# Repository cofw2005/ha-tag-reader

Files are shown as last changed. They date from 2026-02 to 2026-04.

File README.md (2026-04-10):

# Enhanced Home Assistant NFC Tag Reader 🚀

> _**Note:** This project is inspired by [Adonno's Tag Reader](https://github.com/adonno/tagreader). I have first created an original version of Adonno's Tag Reader, and afterwards also added some hardware optimizations for better long-term stability and a slightly modified enclosure specifically for the Type-C D1 Mini._

## 🌟 Overview
This repository provides a refined version of the ESPHome-based NFC Tag Reader. By addressing common electrical limitations and updating the mechanical design for new type-C version D1 Mini board, this project ensures a more robust experience for your smart home automation.

<div align="center">
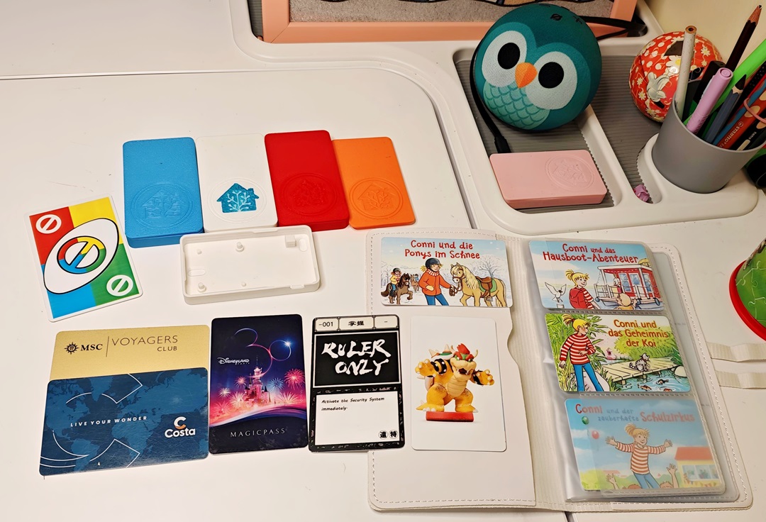
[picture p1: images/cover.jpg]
Family Bucket
  
</div>

---

## 🛠️ Project Evolution & Documentation

I have structured the documentation to guide you through the initial build and the subsequent optimizations:

### 1. [Standard Build Guide](./docs/01.original_build.md)
*Step-by-step instructions following the original Adonno design. Perfect for your first build.*

<div align="center">
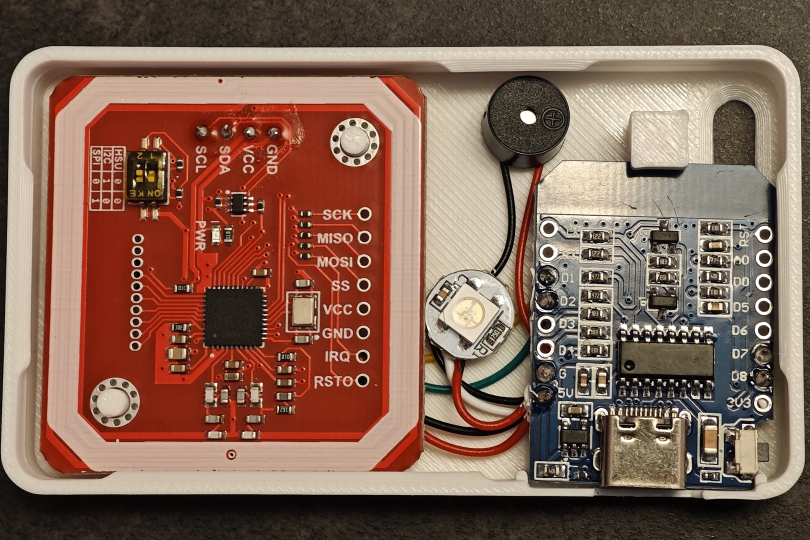
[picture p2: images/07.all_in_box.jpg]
All in box
  
</div>

### 2. [Hardware Optimizations (Recommended)](./docs/02.hardware_optimization.md)
*The "Core" of this repo. Learn what I tested and how I resolved the **1.4V voltage drop** on the buzzer using an S8050 transistor and prevent potential boot issues by reassigning pins.*

<div align="center">
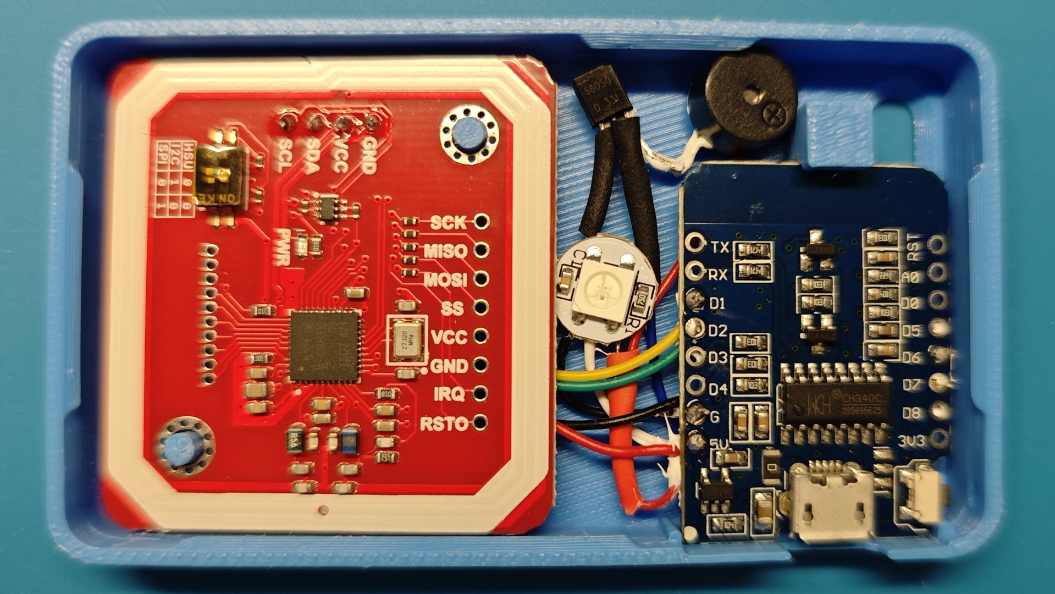
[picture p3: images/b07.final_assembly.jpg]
Final Assembly Result
  
</div>

### 3. [My Applications & Show Off](./docs/03.my_applications.md)
*See the reader in action: custom NFC cards, jukebox automations, and audio triggers.*

<div align="center">
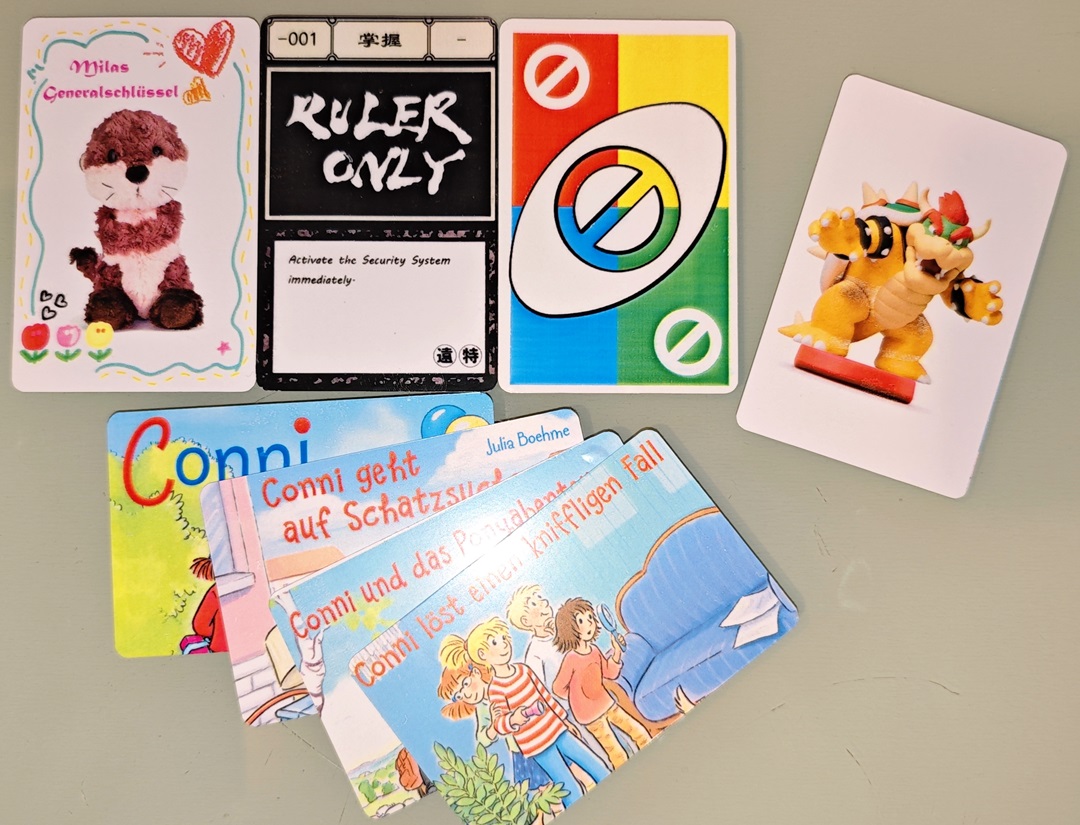
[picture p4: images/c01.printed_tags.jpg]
  
</div>

### 4. Modified Case for type C D1 Mini

I've made some slight modifications to the original STL files from adonno:
1. Adjusted the opening to fit the USB Type-C version of the D1 mini board.
2. I had some minor issues fitting the PN532 board onto the alignment posts, so I shifted one of them by approximately 0.2mm for a better fit.
3. Updated the Home Assistant logo on the top surface to the latest official version.

*See the file in stl folder.*

---

## 🤝 Acknowledgments
- **Adonno**: For the original inspiration and the brilliant base YAML configuration.
- **ESPHome Community**: For the powerful tools that make these projects possible.

---

## 📜 License

This project is licensed under the **GPL-3.0 License** - see the [LICENSE](LICENSE) file for details. 

As a derivative work of [Adonno's Tag Reader](https://github.com/adonno/tagreader), this repository maintains the same GPLv3 terms to ensure the freedom of hardware and software improvements.

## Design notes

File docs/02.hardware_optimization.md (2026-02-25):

# Hardware Optimization: Enhancing Stability & Reliability

> _**Disclaimer:** The original TagReader design works well for most users, and my initial build following that scheme has been operating without any issues. However, based on technical discussions within the community and an analysis of component datasheets, I have proposed the following optimizations from a purely theoretical and long-term reliability perspective. These "patches" aim to further enhance the robustness of the device._

---

## 1. 🔉 Buzzer Drive Optimization (The Transistor Fix)

### The Problem: GPIO Current Limits
In the standard build, the buzzer is driven directly by the **D7 (GPIO13)** pin. 

* **Observation:** During testing, the voltage on D7 dropped to approximately **1.1 ~ 1.6V** when the buzzer was active.

<div align="center">
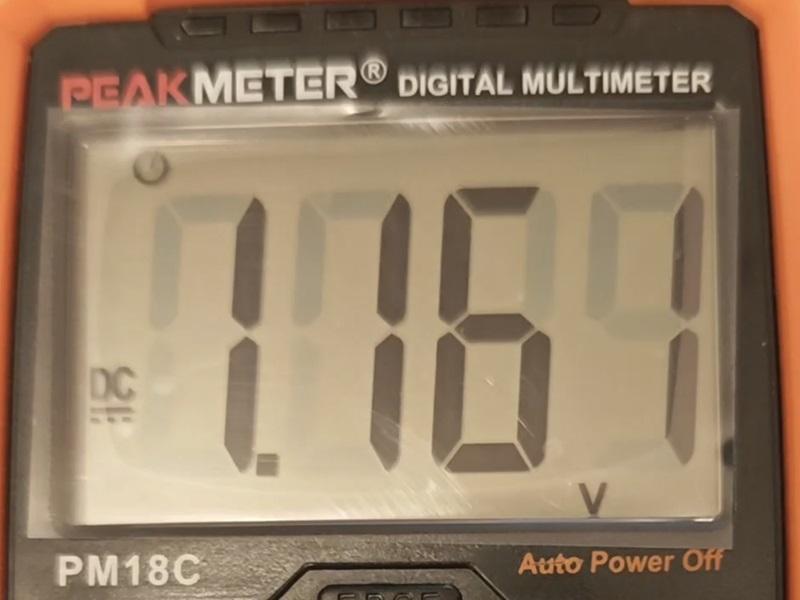
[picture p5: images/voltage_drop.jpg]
  
</div>

* **Analysis:** The ESP8266 pins have a very limited **sourcing current** capacity (approx. 12mA). A typical active buzzer requires 30mA–50mA. This overload results in faint audio and puts stress on the MCU's internal circuitry.

### The Solution: S8050 NPN Transistor
I introduced an **S8050 NPN transistor** to act as an electronic switch.

* **Mechanism:** The D7 pin now only needs to provide a tiny trigger current to the transistor's Base. The transistor then allows the buzzer to draw full power directly from the 5V rail.
* **Simplification:** To keep the build compact, I have driven the Base directly (though a 1kΩ resistor is technically recommended, it can be omitted in this specific low-frequency application to save space).

---

## 2. 🔦 WS2812B Logic Level Shifting (Diode Drop)

### The Problem: 3.3V vs. 5V Logic
While the WS2812B can operate between 3.5V and 5.3V, it is powered by the **5V** rail in this project. Its datasheet specifies that a logic "HIGH" (to the DIN pad) must be at least $0.7 \times V_{CC}$.

* **Calculation:** At 5V supply, $5V \times 0.7 = 3.5V$.
* **Conflict:** The D1 Mini outputs a **3.3V** signal. This puts the signal slightly below the theoretical threshold, which can occasionally lead to flickering or incorrect colors.

### The Solution: Small Signal Diode (1N4148 / 1N4007)
I used a **1N4148** diode (chosen for its small footprint) in series with the LED's VCC line.

* **Mechanism:** The diode creates a voltage drop of ~0.7V. The LED now operates at approx. **4.3V**.
* **New Threshold:** $4.3V \times 0.7 \approx 3.01V$. Now, the D1 Mini's **3.3V** signal is safely above the threshold.

---

## 3. Avoiding Boot Failures (Pin Reassignment)

### The Problem: Strapping Pins & Interference
The ESP8266 has three "strapping pins" that must be in a specific state at boot time:
1. **GPIO15 (D8):** Must be **LOW**.
2. **GPIO0 (D3):** Must be **HIGH**.
3. **GPIO2 (D4):** Must be **HIGH**.

<div align="center">
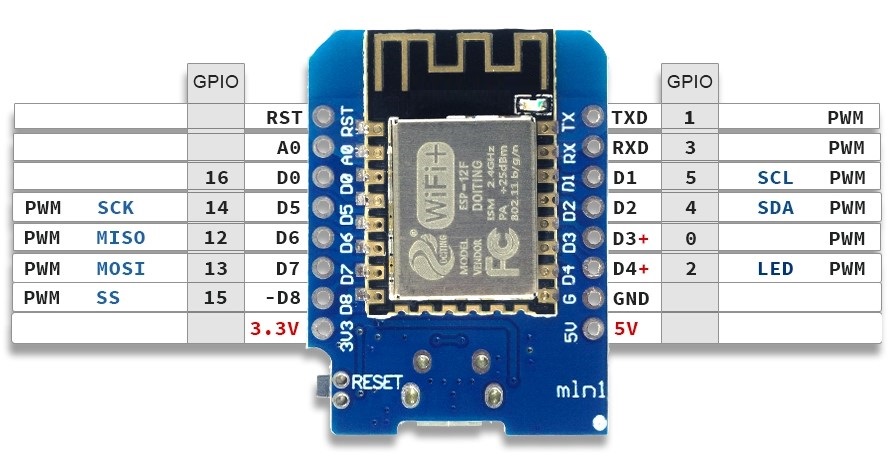
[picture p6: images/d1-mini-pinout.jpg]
  
</div>

In the original design, the LED is often connected to **D8 (GPIO15)**. 
* **The Conflict:** While the WS2812B's DIN (Data In) is internally pulled to GND by default, environmental EMI or leakage current from the 5V rail can occasionally pull this pin HIGH during the millisecond the device powers on. 
* **The Result:** This causes the ESP8266 to enter an invalid boot mode, leading to possibly "hanging" or boot failures.

### The Solution: Shifting to D6 & D7

To avoid the boot-up issues associated with the D8 pin, it is best practice to avoid those strapping pins. I simply shifted the connections over to the neighboring neutral pins. In my optimized build, I reassigned them as follows:

* **Buzzer:** Connected to **D6**.
* **LED Module:** Connected to **D7**.

#### Why this change?
There isn't a strict functional difference between D6 and D7 for these components; both are excellent "neutral" pins that don't interfere with the ESP8266's boot sequence. By moving away from **D8 (GPIO15)** — which must be pulled low at startup — we ensure the device boots reliably every time.

**For a clearer understanding of the optimized circuit, please refer to the schematic below:**

<div align="center">
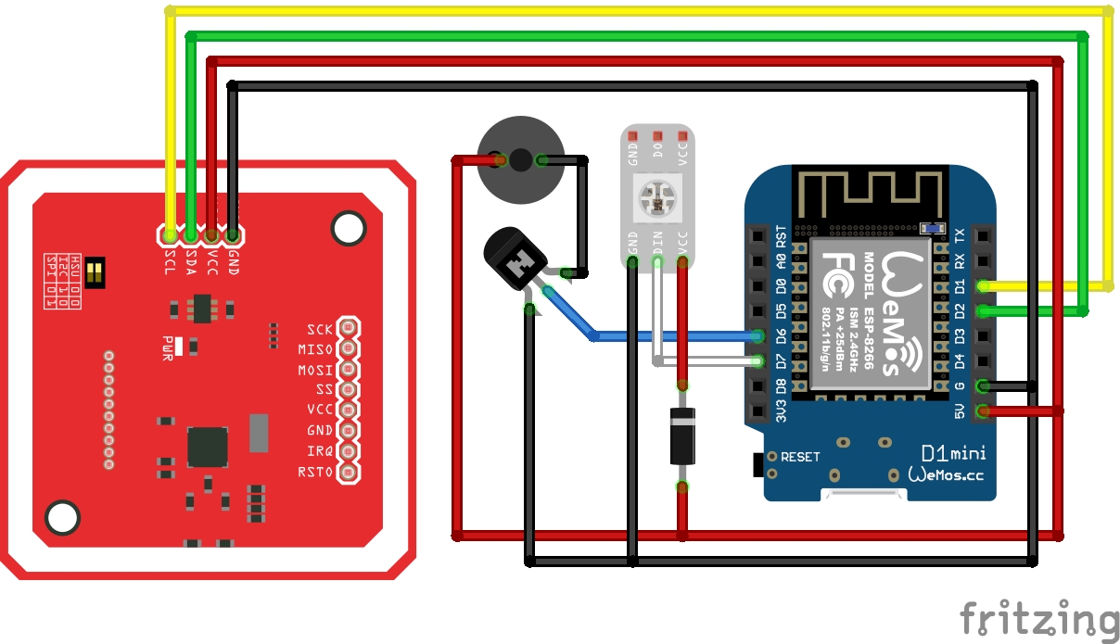
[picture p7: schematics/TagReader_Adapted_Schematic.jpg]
V2.0 Optimized Circuit Schematic
  
</div>

> [!IMPORTANT]
> **Update Your YAML Configuration**
> You need to modify the pin number in the following sections in your `tagreader.yaml` to match the new hardware layout:

**1. For the Buzzer (Shifted to D6):**

```yaml
# Define the buzzer output
output:
  - platform: esp8266_pwm
    pin: D6
    id: buzzer
```

**2. For the LED Module (Shifted to D7):**

```yaml
# Configure LED
light:
  - platform: neopixelbus
    variant: WS2812
    pin: D7
```

---

## 4. V2.0 Build Process & Photos

_This section documents the assembly of the optimized version, focusing on the integration of the transistor driver and the level-shifting diode._

### Step 1: Component Preparation
Before heating up the soldering iron, lay out the new additions alongside the standard components.

<div align="center">
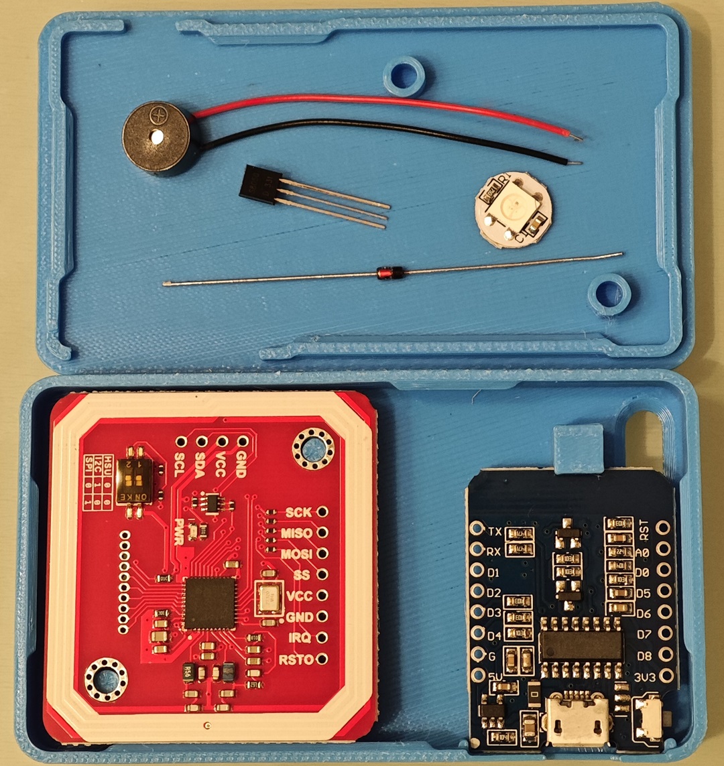
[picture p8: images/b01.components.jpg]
V2.0 Components
  
</div>

* **Added Hardware:** S8050 NPN Transistor and 1N4148 Diode.
* **Pin Shifting:** For this build, we are migrating to **D6** for the Buzzer and **D7** for the LED to ensure a smooth boot sequence.

<div align="center">
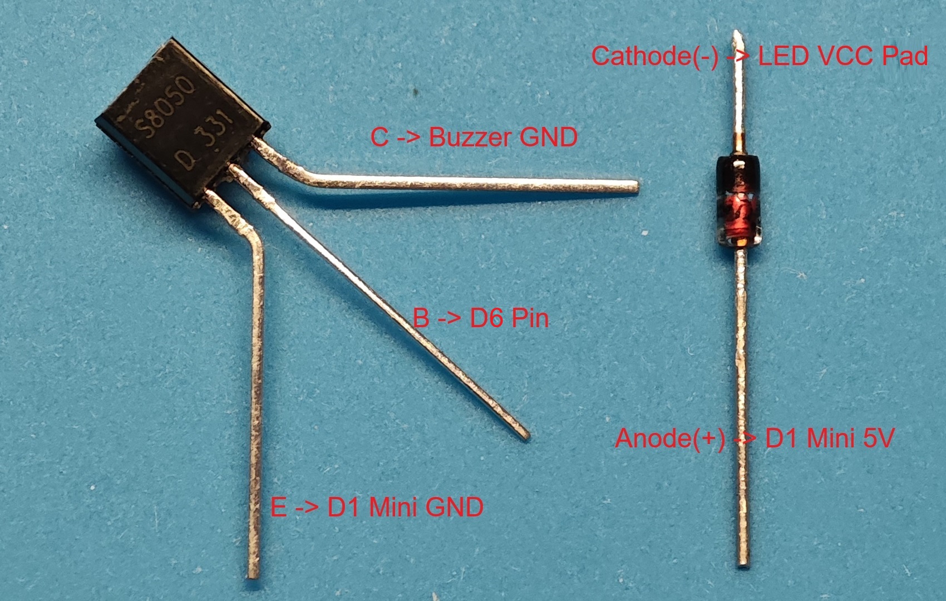
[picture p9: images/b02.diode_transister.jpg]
Diode and Transistor prep
  
</div>

---

### Step 2: Preparing Wires & Pre-cutting
To keep the internals organized within the small 3D-printed case, precise wire management is key.

<div align="center">
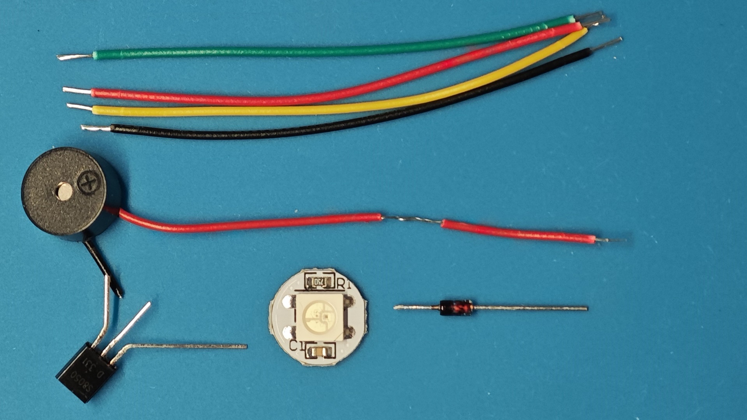
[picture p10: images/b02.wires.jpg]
V2.0 Wire Preparation
  
</div>

* **Wire Set:** Prepare 6 wires (Red, Black, Yellow, Green, White, Blue) at approximately **60mm** each, plus one extra **30mm** black wire.
* **Buzzer Modification:** * Cut the buzzer's **black wire** short, leaving only about **5-10mm**.
    * On the buzzer's **red wire**, strip a small section of insulation about **35mm** away from the buzzer. This will be used to wrap around the Diode's Anode.

---

### Step 3: Soldering the Buzzer & LED Hub
I recommend soldering the peripheral hub (Buzzer + LED + Transistor) first before connecting them to the D1 Mini.

<div align="center">
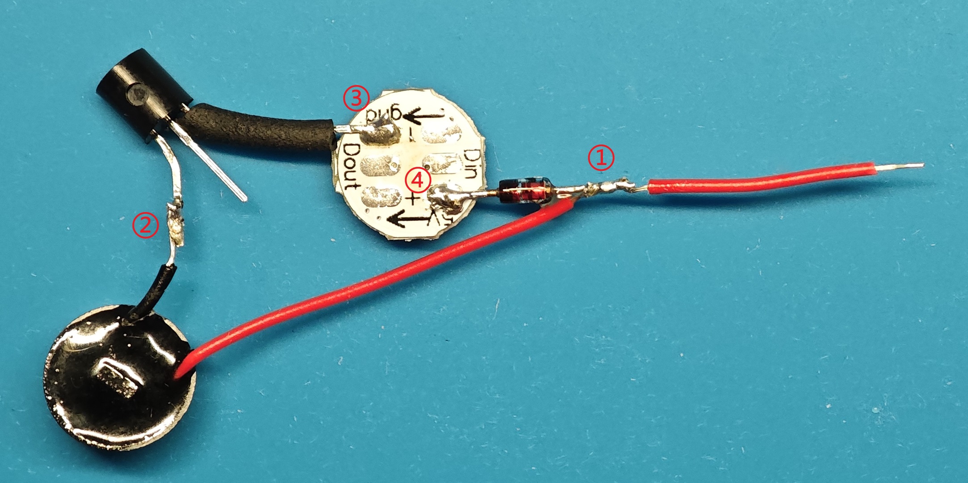
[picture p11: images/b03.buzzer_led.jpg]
Buzzer and LED Soldering Order
  
</div>

Follow this specific soldering order to keep the assembly compact:

1. Wrap the stripped section of the buzzer's **red wire** around the **Anode** of the 1N4148 diode and solder it securely.
2. Solder the shortened buzzer **black wire** to the **Collector (C)** pin of the S8050 transistor.
3. Solder the **Emitter (E)** pin of the transistor to the LED module's **GND OUT** pad. 
    * *Note:* The LED module has both GND IN and GND OUT; they are internally connected. Using the OUT pad here helps with cable routing. 
    * *TIP:* I slipped a small piece of **heat-shrink tubing** over the exposed Emitter pin before soldering to prevent shorts.
4. Solder the **Cathode (black stripe side)** of the diode to the LED module's **VCC IN** pad.
    * *TIP:* After soldering, I slid a larger heat-shrink tube over the entire diode to protect all exposed metal parts and ensure insulation.

---

### Step 4: D1 Mini Pin Soldering (Initial)
Start by connecting the primary signal and ground wires to the D1 Mini. Using a systematic color code helps avoid mistakes later.

<div align="center">
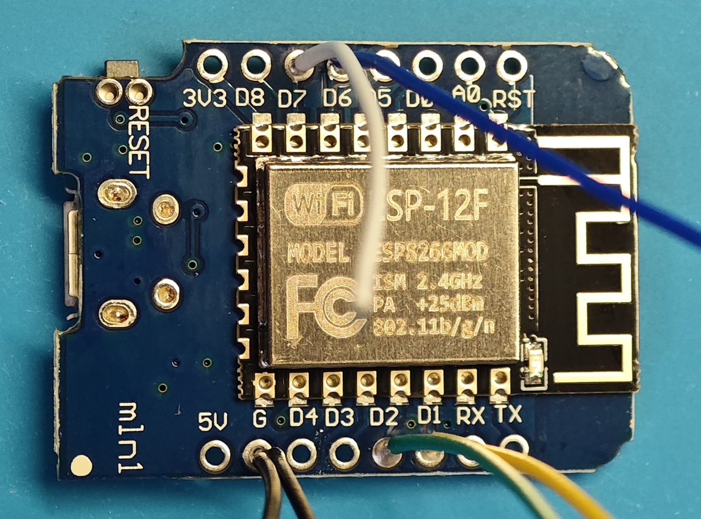
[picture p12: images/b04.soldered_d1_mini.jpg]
Soldered D1 Mini First Stage
  
</div>

* **GND:** Twist **two black wires** together and solder them into the **GND** pad.
* **I2C (PN532):** Solder the **Yellow wire** to **D1** and the **Green wire** to **D2**.
* **Peripherals:** Solder the **Blue wire** to **D6** (Buzzer signal) and the **White wire** to **D7** (LED signal).

---

### Step 5: Finalizing the Hub Connections
Now, connect the D1 Mini's wires to the Buzzer/LED hub we prepared in Step 3.

* **5V Power Rail:** Twist the **Buzzer's red wire** together with the remaining **Red wire** and solder them both into the **5V** pad on the D1 Mini.
* **Buzzer Driver (Blue Line):** Solder the other end of the **Blue wire** to the **Base (B)** pin of the S8050 transistor. 
> [!TIP]
> Remember to slide a small piece of **heat-shrink tubing** onto the blue wire before soldering. Once the joint is cool, slide it over the metal and heat it to secure.
* **LED Data (White Line):** Solder the other end of the **White wire** to the **DIN** pad of the LED module.
* **Ground Bridge:** Solder the remaining **short black wire** to the **GND IN** pad on the LED module.
* **PN532 Final Link:** Finally, solder the four I2C wires (GND, 5V, SDA, SCL) to their respective pads on the PN532 module.

<div align="center">
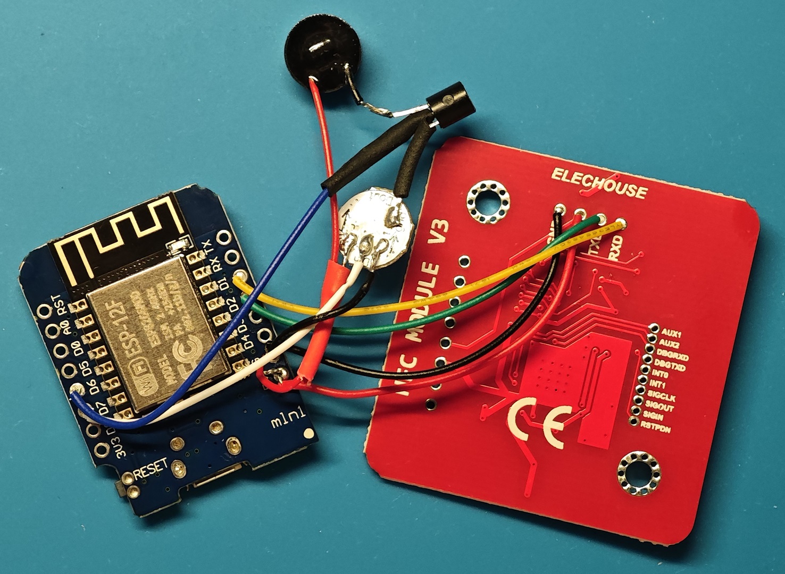
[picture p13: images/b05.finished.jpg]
  
</div>

---

### Step 6: Final Reinforcement & Assembly
With all connections tested and working, it's time to ruggedize the build for daily use.

<div align="center">
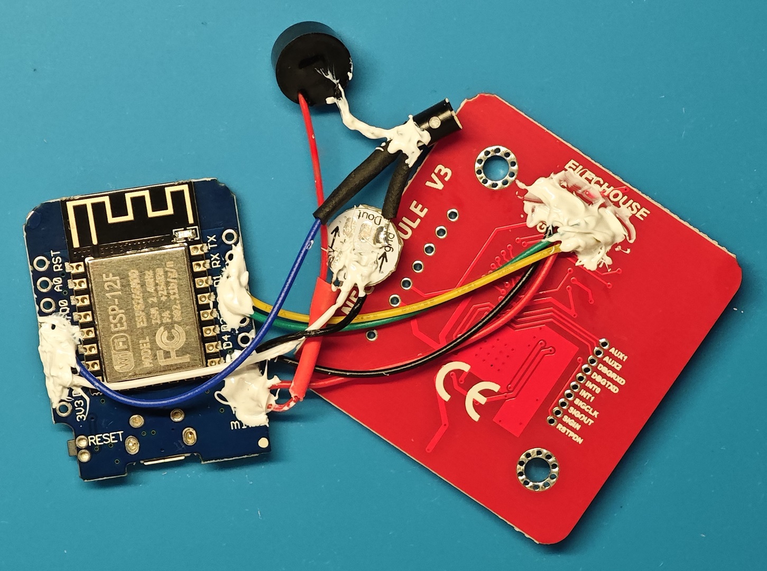
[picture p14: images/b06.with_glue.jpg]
704 Glue Application
  
</div>

* **Insulation & Protection:** Just like the first version, I applied **704 Silicone Glue** to the wire roots on the D1 Mini and the delicate transistor/diode joints. This prevents wires from snapping due to vibration or repeated handling.
* **The "Tight Fit" Challenge:** After the glue is fully cured, carefully tuck the wires into the case. With the addition of the transistor and diode, the interior is noticeably more crowded. 
* **Aesthetics Matter:** The primary reason I chose this specific wiring and routing path was to ensure the **LED module remains perfectly centered** within the enclosure. While it makes the internal cable management more challenging, the symmetrical light output in the final product is well worth the effort.

<div align="center">
  Final Assembly Result
</div>

---

### 💡 Note on Construction
The soldering sequence described above is just one way to achieve the result. As long as your wiring matches the schematic and the pin assignments are correct, feel free to improvise based on your tools and comfort level.

For instance, an alternative could be to **solder the Diode's Anode directly to the 5V pin** on the D1 Mini, and then use that sturdy metal leg as a "bus bar" to attach the other red power wires. This might save even more space depending on how you've routed your cables.

---

## 🚀 Summary of Benefits

1. **Electrical Safety:** The S8050 transistor acts as a buffer; the D1 Mini's GPIO pins are no longer directly driving the inductive load of the buzzer, preventing potential MCU burnout.
2. **Enhanced Audio:** By using a dedicated driver circuit, the buzzer receives a full, stable 5V supply, resulting in a **louder and clearer "beep"** compared to the direct GPIO drive.
3. **Boot-up Reliability:** By migrating to D6/D7, we've bypassed the ESP8266's boot-strap pin requirements, ensuring the device never gets "stuck" during a restart.
4. **Signal Integrity:** The 1N4148 diode provides a precise logic level shift, ensuring the WS2812B receives a clean signal and eliminating the "flickering first pixel" issue.
5. **Centered Aesthetics:** Despite the tight internal space, this specific routing ensures the LED is perfectly centered, providing a professional, symmetrical light glow through the enclosure.

---

## 🛠️ Final Checklist Before Closing

* [ ] **Check your polarities!** Double-check the 1N4148 diode direction (black stripe) and the S8050 pinout (E-B-C) against the schematic.
* [ ] **Short Circuit Prevention:** Ensure all exposed metal joints (especially the transistor legs and diode) are properly insulated with heat-shrink tubing or 704 glue.

---

## 💡 First Power-On & Flashing

Now that the hardware is assembled and the case is closed, it's time to bring the device to life. 

### 🧐 What to Expect on First Boot
When you first plug in the USB cable to flash the firmware, you may notice a specific behavior:

> **Note on Startup Noise:** > During the initial bootup (before the firmware is fully loaded), you might notice a faint **"clicking" or "ticking"** sound from the buzzer. 
> 
> * **Why?** This is due to the "floating" state of the GPIO pins on the D1 Mini during the boot sequence. Without a firm "LOW" signal, the sensitive S8050 transistor may intermittently trigger.
> * **Is it a problem?** No. This is a common phenomenon in transistor-driven circuits. The sound will disappear as soon as the ESPHome firmware initializes and takes control of the GPIO pins.

### ⚙️ Firmware Configuration
Since we migrated the pins for better stability, your `tagreader.yaml` **must** be updated before flashing. If you use the old configuration, the buzzer and LED will not respond.

Ensure your YAML includes these updated pin assignments:

| Component | Old Pin (V1.0) | **New Pin (V2.0)** |
| :--- | :--- | :--- |
| **Buzzer** | D7 | **D6** |
| **LED** | D8 | **D7** |

### 🌙 Managing the PN532 "Ghost Light"
If you look closely at your PN532 board, you'll notice a small red Power LED. Once powered on, it stays lit indefinitely. 

* **The Issue:** This LED is surprisingly bright and will bleed through the 3D-printed enclosure, creating a faint red glow in your room at night.
* **The Fix:** To maintain a "stealth" look and avoid disturbing your sleep, I simply covered the red LED with a small piece of **thick, black double-sided tape** (or electrical tape) before closing the case. This effectively kills the light leak without affecting the board's performance.

---

### ⏭️ Next Step

With these hardware optimizations, you now have a rock-solid, professional-grade Tag Reader that’s built to last. The buzzer is crisp, the power is stable, and the Type-C connection makes it future-proof.

Now comes the most exciting part: **What can you actually do with it?**

Check out **[My Applications & Show Off](./03.my_applications.md)** to see how I transformed these readers into a "Magic Jukebox" for my daughter, implemented "Music Follow Me" logic, and created the "Master Key" for screen-free home automation.

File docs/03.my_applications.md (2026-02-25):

# 🚀 My NFC Tag Applications & Crafting Guide

I've just finished the second iteration of my NFC Tag Readers. I believe that great smart home automation should be more than just functional — it should be engaging, beautiful, and even a bit of an art form. For my latest project, I've spent time perfecting not just the readers, but the physical tags themselves, creating a tactile and aesthetic gateway to our home.

<div align="center">
  Family Bucket
</div>

---

## 01. Crafting the Tags: The Tactile Experience

Before diving into the code, let’s talk about the physical media. The cards are what make the experience "real." I experimented with two methods to achieve a retail-grade look:

<div align="center">
  Printed Tags
</div>

* **The Pro Way (Direct Printing):** Following the Home Assistant Tag page recommendations, I got a **Canon TS705** with a dedicated **PVC card tray** and **inkjet-printable NFC cards**. The result is a professional, smudge-proof finish that feels like a real product. The guide on this page (https://www.home-assistant.io/integrations/tag/) is very comprehensive, just follow the description there.
* **The Budget Way (Adhesive Paper):** I initially bought glossy cards that weren't inkjet-compatible. I recovered by printing the art on adhesive photo paper. 
    * **The Craft:** This method requires a bit more effort. To ensure full edge-to-edge coverage, I print the images slightly oversized (8.8 x 5.6 cm). After applying them to the card, I carefully trim the excess with scissors for a clean, flush finish. It’s a great, cost-effective way to repurpose "wrong" or cheap cards.

* 💡 **Worth mentioning:** Because this Jukebox automation only relies on the **Tag ID** to trigger actions and doesn't require writing specific data to the chip, you can repurpose almost any NFC card you have lying around. Old hotel key cards, theme park tickets, or even some transit cards (ISO14443A) can be turned into music tags. Just scan them once, grab the ID, and map it in your configuration!

It's time to create your own artworks! Happy printing!

> [!TIP]
> **The Hybrid "Amiibo-Automation" Card**
>
> For Nintendo Switch players, **NTAG215** cards offer a brilliant "Dual-Purpose" opportunity. Since most Home Assistant automations rely solely on the unique **Tag ID** as a trigger, the actual data stored on the card's memory doesn't interfere with your smart home logic.
>
> **Double the Fun:** You can flash the card with **Amiibo data** first, then use it in Home Assistant. I print the **Album Art** on the front and the **Amiibo character artwork** on the back. 
> One single card now leads a double life: It’s a collectible character in *Super Mario Galaxy* on your Switch, and a magic music key for your Sonos. 

> [!IMPORTANT]
> _Note: Be sure to flash the Amiibo data first, as this process permanently "locks" the card's data partition — but don't worry, the Tag ID remains readable for Home Assistant!_

---

## 02. Primary Application: A Magic Jukebox for My Daughter

While the most common use case for tags is a Jukebox, I built for my daughter. She loves her collection of audiobooks and children's stories. Instead of using a screen, she simply picks a card with the book's cover and taps it on the reader.

<div align="center">
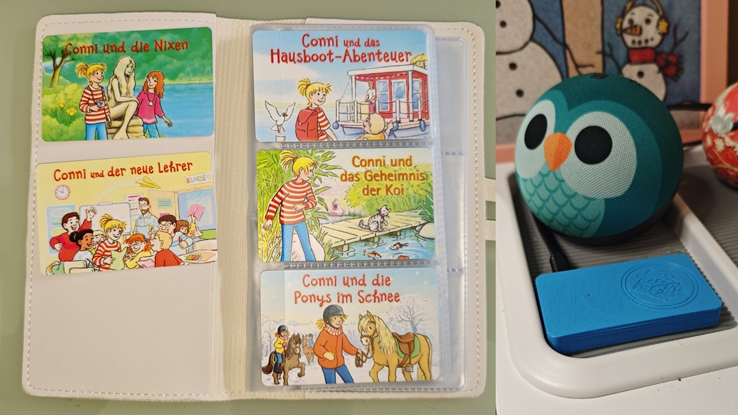
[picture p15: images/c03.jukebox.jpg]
Jukebox
  
</div>

### "Music Follows Me" - Smart Playback Logic
I wanted to push the boundaries of the standard automation to make it a little more "smart." Since I have now two Sonos speakers in multiple rooms, I added a **"Music Follows Me"** (Smart Transfer) feature in the automation to make the experience seamless as she moves around the house.

**How it works:**
When a tag is scanned, the automation checks if that specific album is already be played on another media player:
* **The Hand-off:** If it's playing elsewhere, it uses `music_assistant.transfer_queue` to move the playback (and the exact progress) to the current room.
* **Fresh Start:** If not active, it starts the media from the beginning.

I have already planned for my next project: a high-fidelity media player based on the **ESP32-S3 + PCM5102A (I2S DAC)**. This "Music Follow Me" logic is particularly useful here, as it will allow me to seamlessly switch the playing queue between my Sonos system and my own custom-built hardware. 

You can find the YAML for the automaction below:

```yaml
#+++++++++++++++++++++++++++++++++++++++++++++++++++++++++++++++++#
# NFC-Triggered Music Playback
#+++++++++++++++++++++++++++++++++++++++++++++++++++++++++++++++++#
- alias: TagScan_PlayMusic
  max_exceeded: silent
  variables:
    # Map scanner device ID to media player entity ID
    media_players:
      afba1824b174607d734bxvxv0896dcf0: media_player.sonos_livingroom_mass
      36efe8f67c6b9gegr207cc9afb408126: media_player.sonos_kidsroom_mass
    # All my Music Assistant media players
    media_player_mass_list:
      - media_player.sonos_livingroom_mass
      - media_player.sonos_kidsroom_mass
      - media_player.sonos_office_mass
    # Map tag ID to content
    tags: !include tag_list.yaml
  triggers:
    - trigger: event
      event_type: tag_scanned
  conditions:
    # Test that we support this device and tag
    - "{{ trigger.event.data.tag_id in tags }}"
    - "{{ trigger.event.data.device_id in media_players }}"
  actions:
    - variables:
        target_player: "{{ media_players[trigger.event.data.device_id] }}"
        media_id: "{{ tags[trigger.event.data.tag_id].media_id }}"
        media_type: "{{ tags[trigger.event.data.tag_id].media_type }}"
        source_player: >-
          {% set active_players = media_player_mass_list | select('is_state', 'playing') | list %}
          {% set found = namespace(entity_id=none) %}
          {% for p in active_players if p != target_player %}
            {% if state_attr(p, 'media_album_name') == media_id %}
              {% set found.entity_id = p %}
            {% endif %}
          {% endfor %}
          {{ found.entity_id if found.entity_id is not none else '' }}
    - choose:
        # If the album is being played on another media player, transfer the queue to target player
        - conditions: "{{ source_player != none and source_player != 'None' and source_player != '' }}"
          sequence:
            - action: music_assistant.transfer_queue
              target:
                entity_id: "{{ target_player }}"
              data:
                source_player: "{{ source_player }}"
                auto_play: true
      default:
        # By default, start fresh playback on the target media player
        - action: music_assistant.play_media
          target:
            entity_id: "{{ target_player }}"
          data:
            media_id: "{{ media_id }}"
            media_type: "{{ media_type }}"
    # timeout before we allow processing next scan
    - delay: 2
```

> [!TIP]
> **The Code Structure:**
> I keep my configuration clean by decoupling the data from the automation. I store all tag mappings in a separate `tag_list.yaml`.
> This way, whenever I want to add a new album or change a tag, I only need to edit the simple data file instead of digging through a long and complex `automation.yaml` to find the right lines. It makes the whole system much easier to maintain and scale.
>
> *Of course, a quick "Reload Automations" in Home Assistant is still required after editing `tag_list.yaml` to make the new mappings live!*

Example of `tag_list.yaml`:
```yaml
# Example: List of all tags for Automation TagScan_PlayMusic
04-A3-74-83-3B-3A-4C:
  media_id: Conni Und Das Hausboot-Abenteuer
  media_type: album
04-D3-F6-7F-3B-3A-4C:
  media_id: Conni und das Abenteuer in der Wildnis
  media_type: album
04-13-A0-97-3B-3A-4C:
  media_id: Conni und der beste Spürhund der Welt
  media_type: album
```
---

## 03. Beyond Music: Physical Automation Triggers
NFC tags are incredibly reliable "physical buttons" for routines where voice or apps feel clunky:

* **Security Control:** A hidden tag near the door allows us to arm the security system or toggle "Away Mode" with a simple tap.
* **Notification Management:** I have a "Clear Notifications" tag. Scanning it instantly acknowledges and clears all pending alerts across our dashboards and phones.
* **The "Universal Key" for Kids:** Basically, NFC tags can replace any complex dashboard operation — which is a game-changer for children who don't have (or shouldn't have) their own phones. I gave my daughter a "✨Master Key🗝️" card: whatever new automation she dreams up, I simply program it to her card. It gives her a sense of magic and control over her own environment without needing a screen.

<div align="center">
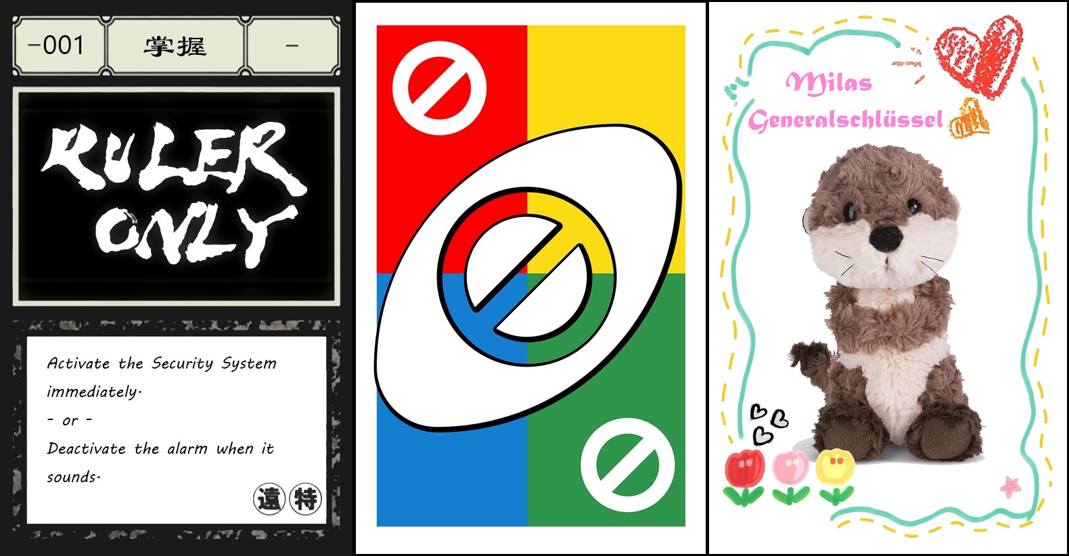
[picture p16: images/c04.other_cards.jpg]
  
</div>

### 💡 Quick Guide: Two Ways to Trigger Automations via NFC

When setting up your logic in Home Assistant, you generally have two paths depending on how flexible you want your system to be:

1. **The Tag Trigger (Simple & Direct):**
   This is the standard way. You select "Tag" as your trigger type and specify a **Tag ID** and/or a **Device ID**.
   * **Best for:** One-off automations like "Arm Security" or "Toggle Desk Light."
   * **Pros:** Easy to set up via the UI; very reliable for fixed locations.

```yaml
automation:
  triggers:
    - trigger: tag
      tag_id: A7-6B-90-5F
      device_id: 0e19cd3cf2b311ea88f469a7512c307d
```

2. **The Event Trigger (Dynamic & Scalable):**
   This method listens for the `tag_scanned` event across the entire system.
   * **Best for:** Complex setups like a Jukebox logic.
   * **How it works:** You use an Event Trigger to capture any tag scan, then use the `tag_id` and `device_id` from the event data to decide what happens next (e.g., looking up in your tag list).
   * **Pros:** Much easier to manage 50+ tags; allows you to identify *which* device scanned the tag to route music correctly.

```yaml
automation:
  triggers:
    - trigger: event
      event_type: tag_scanned
  conditions:
    # Test that we support this device and tag
    - "{{ trigger.event.data.tag_id in tags }}"
    - "{{ trigger.event.data.device_id in media_players }}"
```

---
<div align="center">
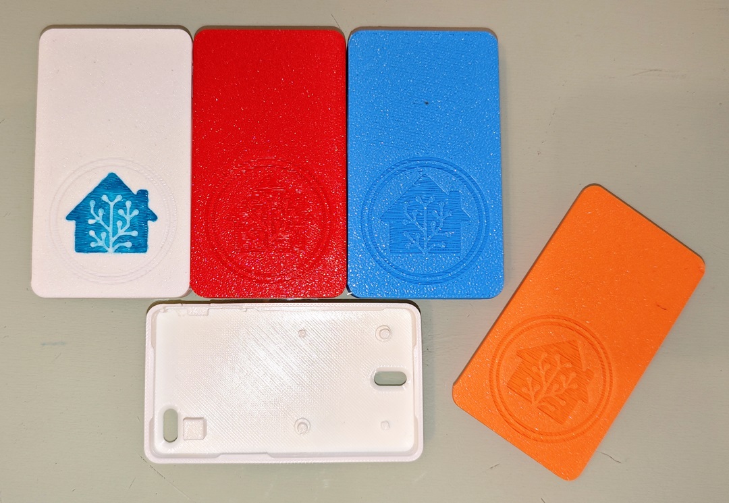
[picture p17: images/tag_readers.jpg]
More Tag Readers
  
</div>

🚀 Anyway, that’s my V2.0 journey! I'm super curious—what are you guys tapping your tags for? Any crazy automation ideas? 🙌

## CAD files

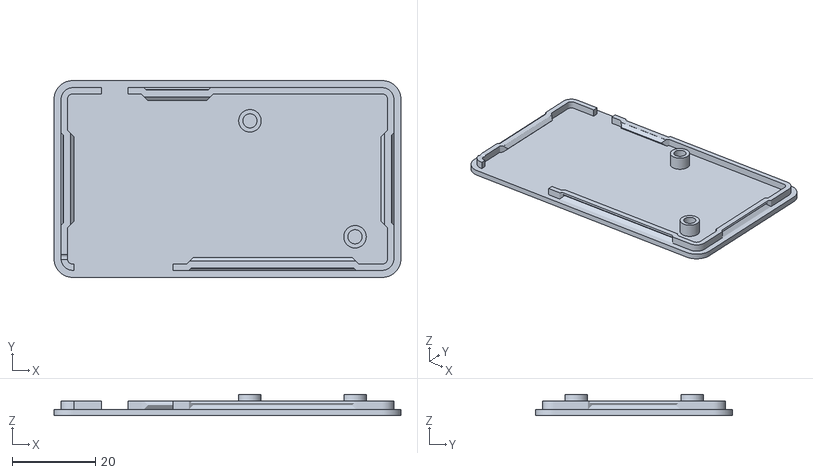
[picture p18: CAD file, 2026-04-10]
stl/Cover-new-logo-vertical.stl
83.2 x 47.2 x 5.10

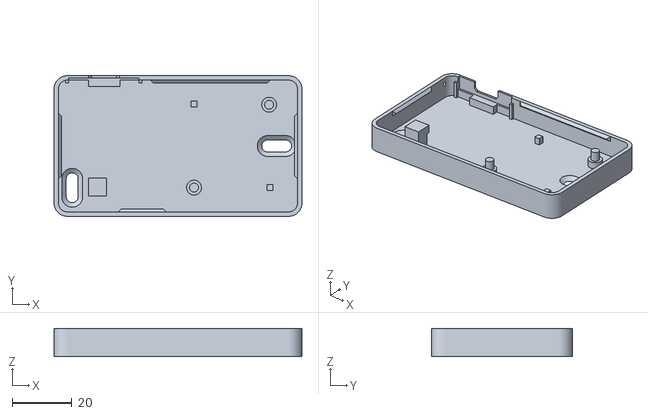
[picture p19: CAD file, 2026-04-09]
stl/Case-2_TypeC.stl
83.2 x 47.2 x 9.50

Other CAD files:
stl/Cover-new-logo-horizontal.stl

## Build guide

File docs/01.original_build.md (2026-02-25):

# Standard Build Guide (Version 1.0)

_This guide walks you through the initial assembly of the NFC Tag Reader following the standard Adonno design. This version serves as the baseline foundation before we apply further hardware optimizations in subsequent chapters._

---

## 1. Preparation & Parts List
Before heating up your soldering iron, ensure you have all the necessary components.

<div align="center">
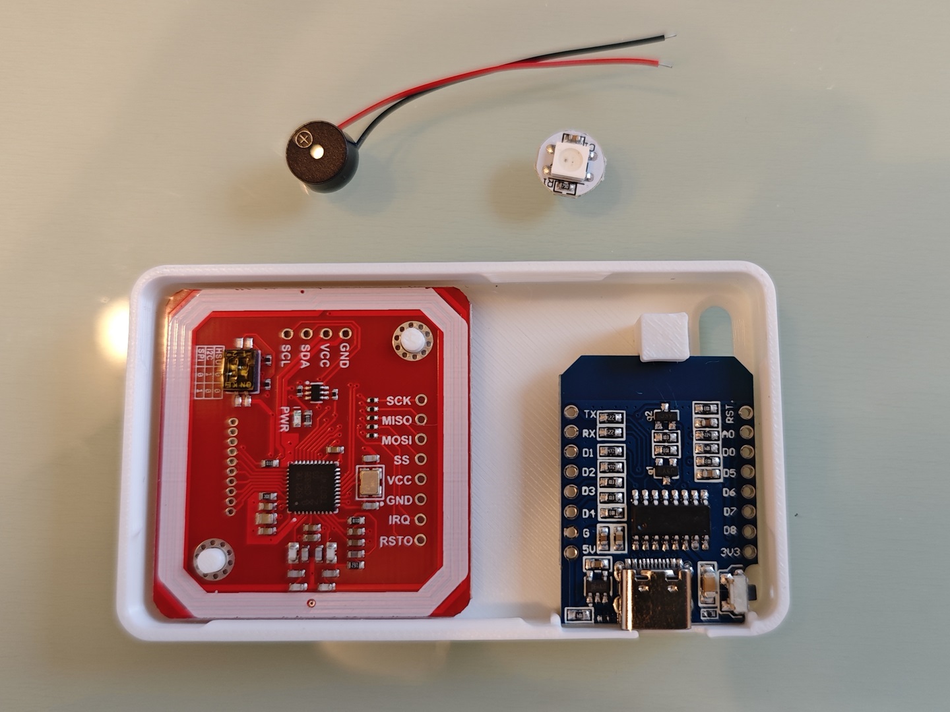
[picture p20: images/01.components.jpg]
Components
  
</div>

* **D1 Mini Board:** Note that the original adonno's design uses the Micro-USB version. I mistakenly purchased the **Type-C version**, which leads to a misalignment with the case opening as shown below.
    * **Solution:** If you have the same issue, you can either enlarge the opening with a hobby knife or use my revised STL file (`Case-2_TypeC_Adapted.stl`) which has been adjusted for the Type-C port dimensions.

<div align="center">
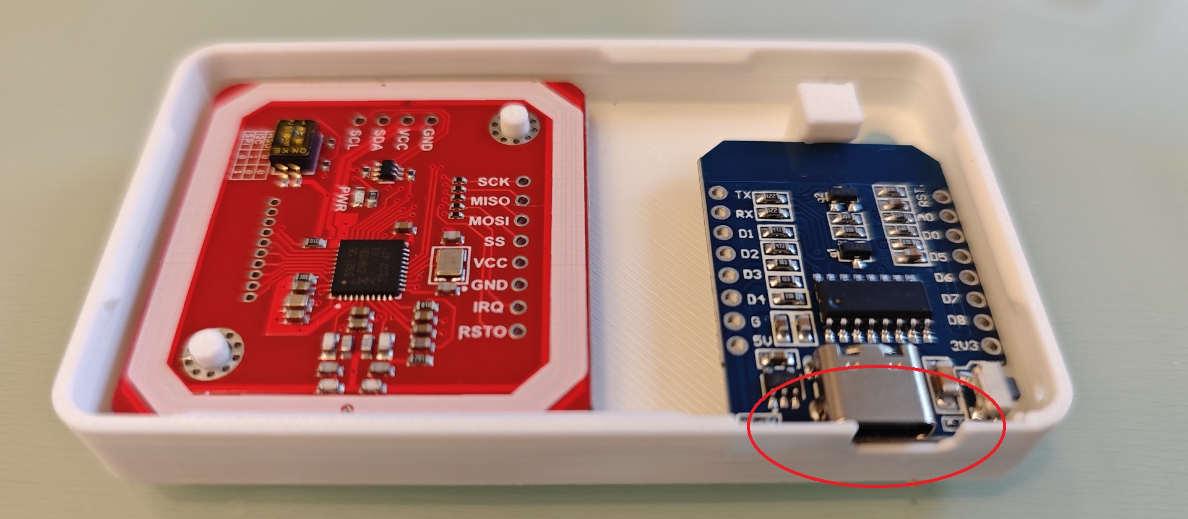
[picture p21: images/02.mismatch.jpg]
Opening
  
</div>

* **NFC Module:** PN532 (Standard version, no fitment issues).
* **Buzzer:** Ensure you use a **5V Active Buzzer (Model 9042)**. I opted for the **pre-wired version**, which saves two soldering points and simplifies installation.
* **WS2812B RGB LED Module:** Do not buy individual LED components. Use a **WS2812B Mini Board**. These come in various shapes; I am using a circular PCB version, which fits perfectly in the logo area.

---

## 2. Preparing the Wiring & "Middle-Strip" Technique
To keep the build as compact as possible, wire management is crucial. My strategy involves a "Daisy-Chain" ground to minimize the number of wires returning to the D1 Mini.

<div align="center">
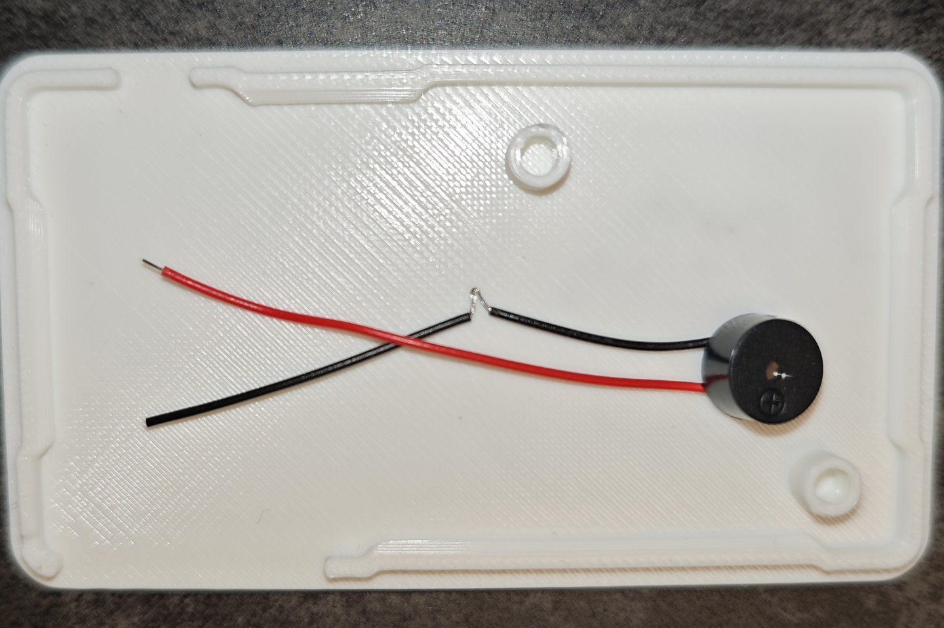
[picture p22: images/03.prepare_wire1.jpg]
  
</div>

* **The Ground Splicing:** To save space, the Buzzer and LED module share a single GND path. 
    * **Method:** Strip a small section of the Buzzer's GND wire approximately **15mm** away from the buzzer. Twist this section together. This joint will be soldered directly to the **GND pad of the LED module**.
* **Wire Specifications:**
    * **PN532 (4 wires):** Total length **55-60mm**. Strip 3-5mm at both ends for soldering.
    * **LED DIN (1 wire):** **45-50mm**.
    * **LED 5V Power (1 wire):** **25-30mm**.

<div align="center">
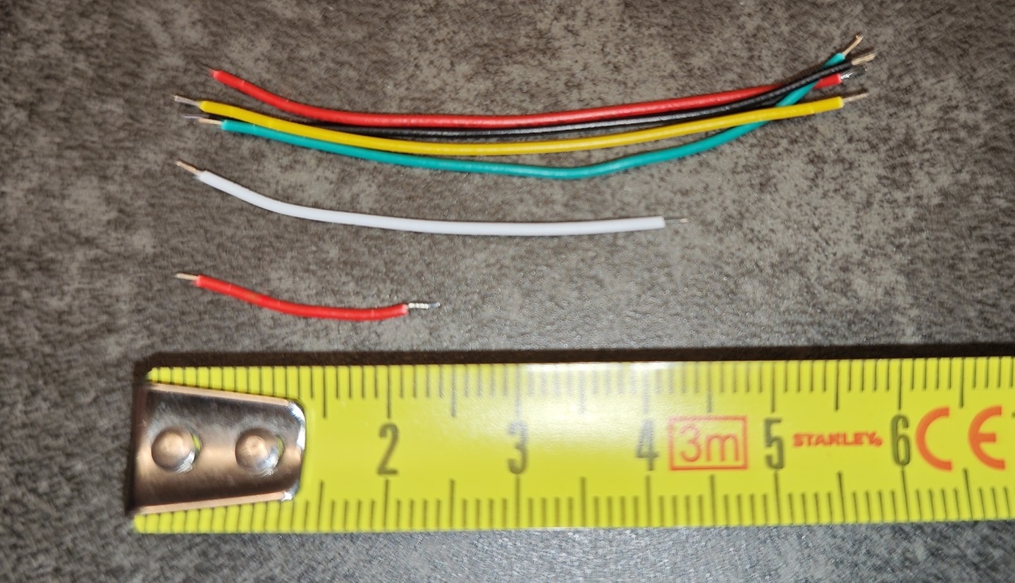
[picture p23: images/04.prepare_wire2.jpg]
  
</div>

---

## 3. Soldering & Component Reinforcement
Follow the wiring diagram carefully. To maintain a clean layout, I recommend soldering the components in the following sequence:

1.  **D1 Mini Base Pins:** Start by soldering **D1, D2, D8**, and **5V**. 
    * **Tip (Power Hub):** For the 5V pin, twist the ends of the two red power wires (one long for PN532, one short for LED) together. Insert this twisted pair through the 5V hole and solder them as a single joint to ensure a solid power distribution hub.
2.  **LED & Buzzer GND:** Solder the pre-stripped "middle section" of the buzzer's black GND wire to the **GND pad** of the LED module (as shown in the photo above).

<div align="center">
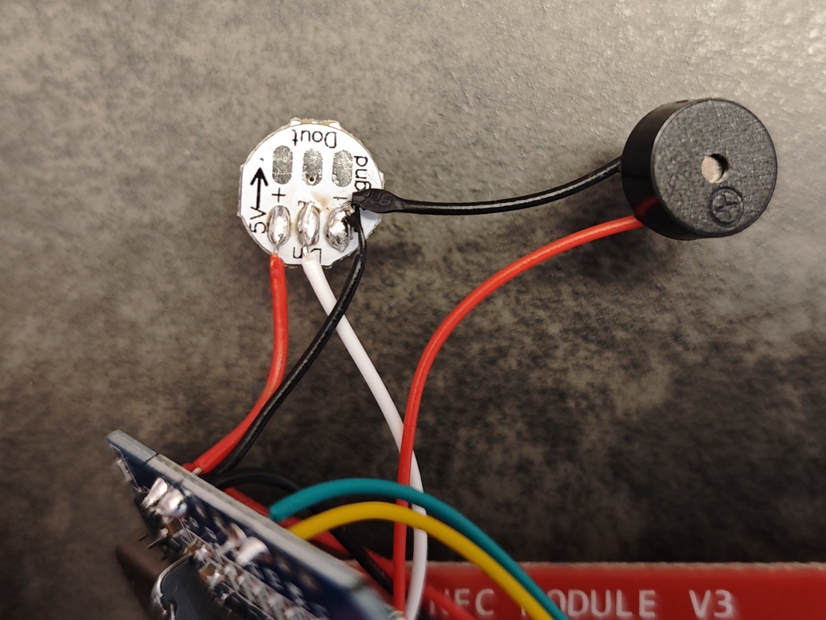
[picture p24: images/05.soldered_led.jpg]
LED Module
  
</div>

3.  **Solder Buzzer:** Solder the wires from Buzzer to the **D7** (Buzzer Signal) and **GND** pins on the D1 Mini. 
    * **Tip (GND Hub):** For the GND pin, twist the ends of the two black GND wires (one long for PN532, one for LED & Buzzer) together. Insert this twisted pair through the GND hole and solder them as a single joint to ensure a solid GND hub.
4.  **Solder LED Module:** * Solder the **DIN** wire (from D1 Mini D8) and the short **5V** wire to the LED module's respective pads.
5.  **Final Step:** Solder the four interface wires to the **PN532** module.

<div align="center">
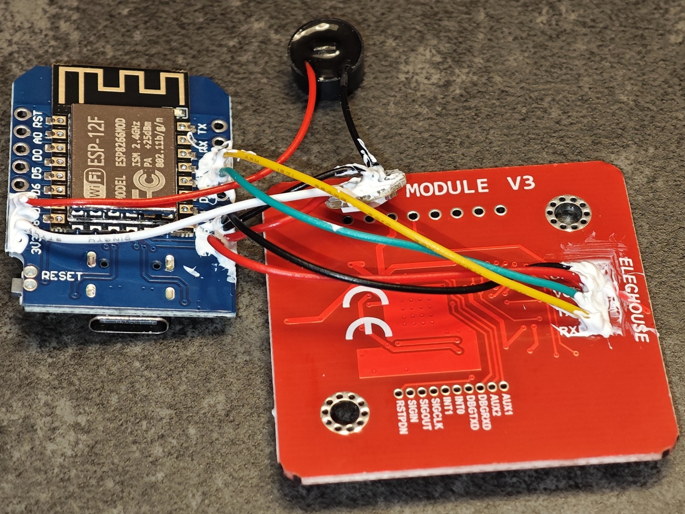
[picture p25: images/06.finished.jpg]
Finished Soldering
  
</div>

> **Structural Reinforcement:** After soldering, I applied a small amount of **704 RTV silicone glue** to the base of the wires where they meet the PCB. This provides **strain relief**, preventing the thin copper strands from snapping due to bending during assembly.

---

## 4. Final Fitment & Finishing Touches
Once the 704 glue has fully cured and the connections are secured, it's time for the final assembly.

<div align="center">
  All in box
</div>

1.  **Enclosure Assembly:** Carefully tuck the components into the 3D-printed case. Start with the PN532 at the top, followed by the D1 Mini. 
2.  **Case Alignment:** As you can see in the photo, the modified Type-C opening now fits the cable, though a small gap remains on the right side due to the manual adjustment.

<div align="center">
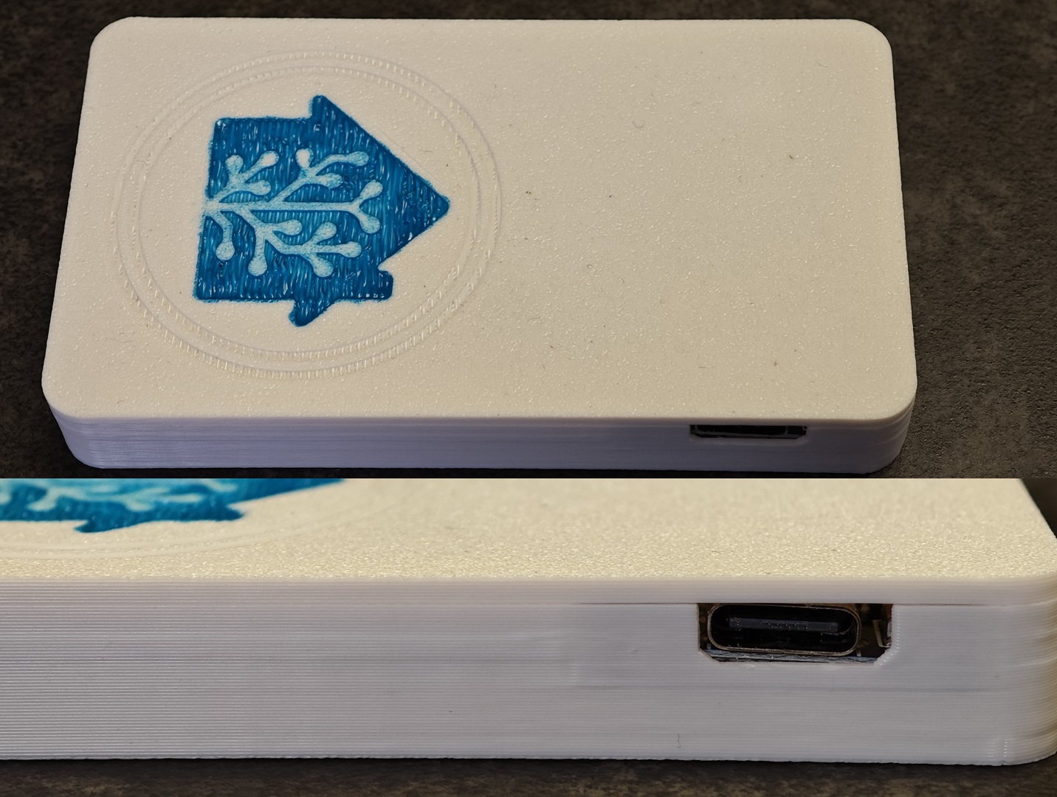
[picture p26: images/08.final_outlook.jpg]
Outlook
  
</div>

3.  **Aesthetic Touch:** I printed the case only in one color. To make the reader stand out, I filled the **Home Assistant logo** on the lid with colored paint, giving it a high-contrast, custom look.

---

### 💡 First Power-On & Flashing
* **Initial Observation:** In my specific case, when I first powered on the device, the **WS2812B LED stayed bright white**. This continued until the firmware was successfully flashed. If you encounter the same situation, don't panic—it may just be the uninitialized state of the LED.
* **Flashing the Firmware:** I used the **ESPHome Add-on in Home Assistant**. For the configuration, I used Adonno's original `tagreader.yaml`, only modifying the `substitutions` section, WiFi details, and API passwords.
* **Final Result:** Once the "Success" message appeared in the logs, I performed a power cycle (unplug and replug the Type-C cable). The reader then initialized perfectly and began working as expected.

---

### ⏭️ Next Step
To my experience, this standard build has been working perfectly so far. However, I did notice some potential **electrical limitations** during the process, which led me to implement several improvements when building my second Tag Reader.

Check out **[Hardware Optimization](./02.hardware_optimization.md)** if you are interested in spending a bit more time to build a more robust and stable version, featuring an **S8050 NPN Transistor** driver and **1N4148 Diode** voltage shifting.
